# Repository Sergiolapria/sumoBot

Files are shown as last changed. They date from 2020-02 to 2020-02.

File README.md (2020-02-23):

# ROBOT DE MINISUMO

	Documentacion necesaria para la construccion de un robot de minisumo lo mas sencillo posible.

# ELECTRONICA
	
	Contiene la siguiente electronica:
-Modulo VL53L0X: para la medidion de la distancia a los objetos delante del robot.
-2 módulos de IR de siguelineas: seran los encargados de detectar en la parte del Dohyo en la que se encuentra.
-Driver L9110: Controla los motores.
-Arduino nano: posiblemente para comenzar la mejor opcion debido a su pequeño tamaño.

# DISEÑO

	El robot consta de 3 piezas:
-Chasis: En el iran ubicados los sensores IR, el driver de motores y los motores.
-Parte superior: Funciona  como sijeccion de los motores y llevara el sensor VL530LX asi como la pieza adaptador del Arduino nano.
-Adaptador: Alojara el arduino nano.

# LIBRERIAS:

-VL53L0X
-L9110.h( esta ultima la saque de http://bricolabs.cc/wiki/index.php?title=Sapoconcho)

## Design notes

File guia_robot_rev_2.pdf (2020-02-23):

GUIA PARA MONTAJE DE ROBOT MINISUMO DE MAKERSASTURIAS REV:2

Montaje de sensores IR:
Este sensor es el encargado de leer el suelo, es un sensor óptico reflexivo, la cantidad de luz reflejada depende del color por lo que podremos distinguir entre zonas claras y oscuras de un objeto. Contiene 2 partes, un diodo IR y un fototransistor en el cual incide la luz reflejada. A continuación se muestra la placa que acompaña a nuestro sensor. En el vemos que a parte de los pines de alimentación tenemos dos pines mas, el marcado por A0 es la señal analógica la cual da un valor en función de la luz que incide en el fototransistor, estas placas incluyen un amplificador operacional LM293 por lo cual nos dará una lectura digital cuando se supere cierto umbral.

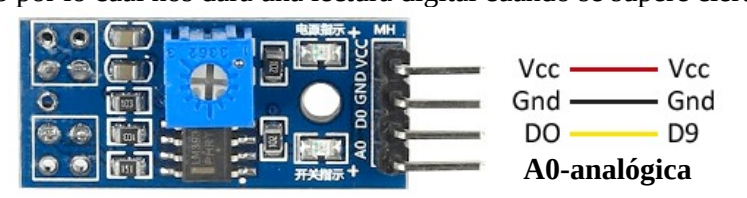
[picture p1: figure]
A0-analógica

Su ubicación es en el chasis colocandolos de la siguiente forma:

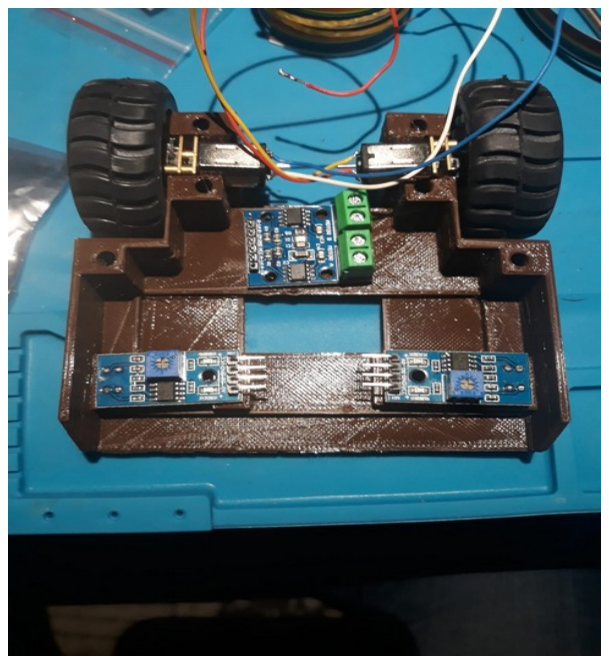
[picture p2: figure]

Para cablear y con el fin de descubrir por nosotros mismos la diferencia de trabajar con señales digitales y con señales analógicas cablearemos las dos.
El cableado al arduino ira de la siguiente manera:
MODULO IR | ARDUINO NANO
PIN | DESCRIPCIÓN | PIN
1-izquierda | Pin analógico izquierda | A0
2-izquierda | Pin digital izquierda | D2 | Pin digital 2(con la intención de habilitar int)
3-GND | Masa
4-Vcc | Alimentación 5V
1-derecha | Pin analógico derecha | A1
2-derecha | Pin digital derecha | D3 | Pin digital 3(con la intención de habilitar int)
3-GND | Masa
4-Vcc | Alimentación 5V

Montaje de sensor VL53L0X:
El VL53L0X es un sensor de distancia infrarrojo láser que mide un rango de distancias de 50 mm a 2000 mm, tiene mejor precisión a los sensores de ultrasonidos e infrarrojos y no se ve interferido por el ambiente como reflejos o ecos. Al ser láser tiene un ángulo de medición estrecho,
Twitter: @SergioPria | Pag. 1 de 6

REV:2

por lo cual solo leeremos la distancia que esta justamente en frente del sensor. Este ángulo de medición es de 25º, se traduce que a 1 m tenemos un área de 0,5 mm de diámetro.
Su colocacion en la parte superior sera de la siguiente forma:

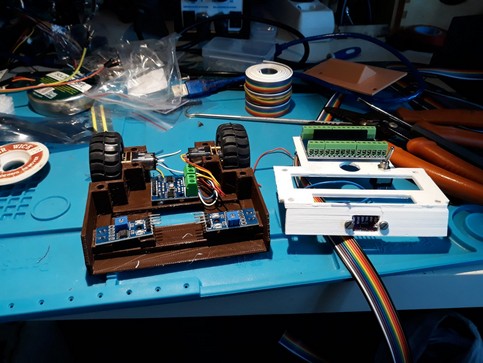
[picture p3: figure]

MODULO VL53L0X | ARDUINO NANO
PIN | DESCRIPCIÓN | PIN
Vin | Alimentación 3.3V
GND | Masa
SCL | | A5
SDA | | A4

Para el manejo del sensor VL53L0X utilizaremos la librería VL53L0X la cual se puede descargaren el repositorio de librerías del IDE de arduino. También se podría utilizar la librería de arduino. Montaje driver motores:
El driver esta basado en el puente en H L9110S el cual sirve para controlar un motor entre 2.5V y 12V con un consumo máximo de 800 mA pero la placa va provista de 2 integrados.
Como pines para controlar los motores utilizaremos los pines PWM del arduino nano D6,D9,D10 y D11.
La alimentación la haremos directamente desde la batería LiPo.
Para el manejo de los motores utilizaremos la librería de felixstdp realizada para el robot sapoconcho https://github.com/felixstdp/sapoconcho.
El cableado final quedara de la siguiente figura:

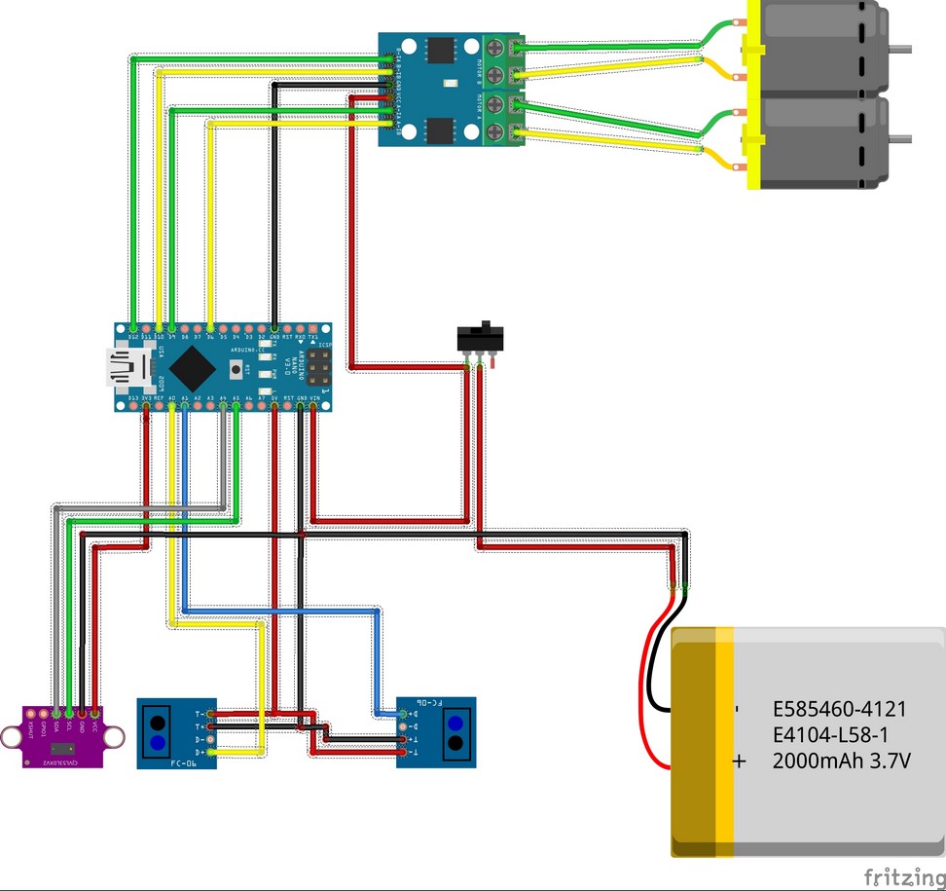
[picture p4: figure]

REV:2

Cableado:

Antes de comenzar a cablear debemos de disponer las diferentes placas que constituyes nuestro robot. En la parte inferior, yo lo llamo chasis, debemos de colocar los sensores IR, el driver para los motores y los motores, tal y como se muestra en la siguiente fotografia:

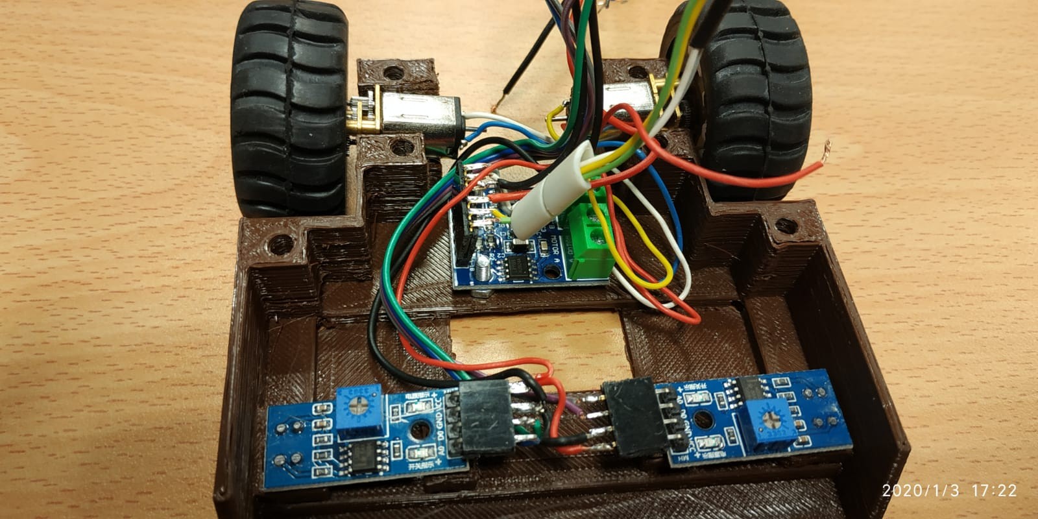
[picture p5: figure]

Es recomendable pegar los cables bien a la pared derecha o izaquierda con tal de que no nos estorben.
El siguiente paso seria soldar el interruptor y el conector de la bateria:

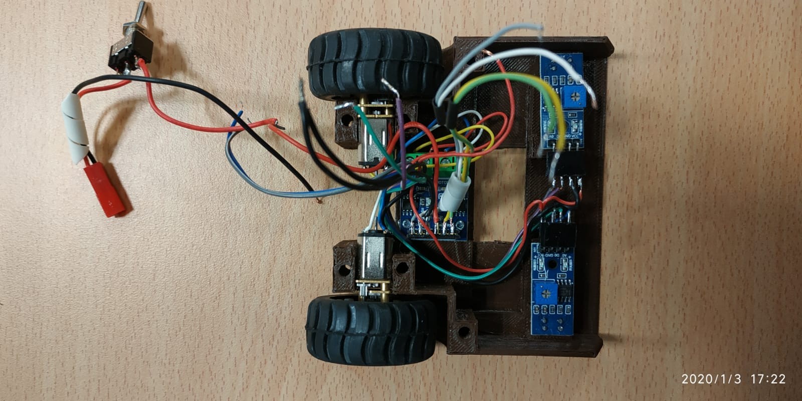
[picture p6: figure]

Si los sensores IR y el driver esta soldado sacamos los cables para arriba, ya que van a ir conectados al arduino nano, que va a ir a la parte superior.

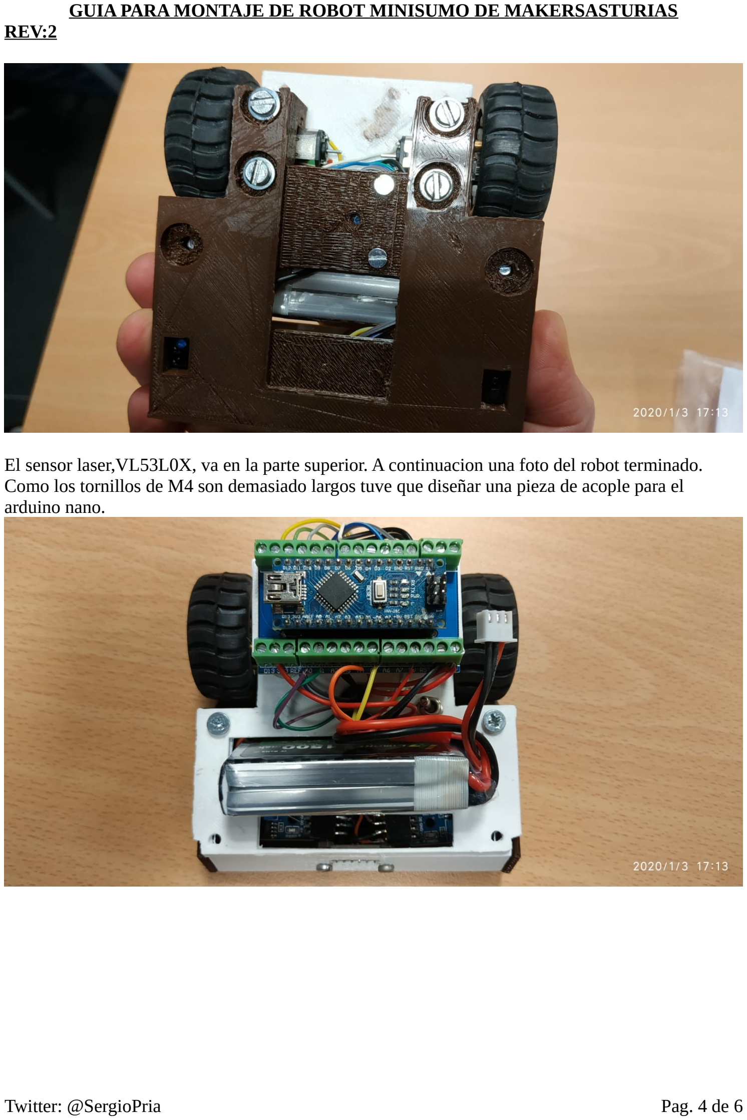
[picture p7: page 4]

REV:2

El sensor laser,VL53L0X, va en la parte superior. A continuacion una foto del robot terminado. Como los tornillos de M4 son demasiado largos tuve que diseñar una pieza de acople para el arduino nano.

REV:2

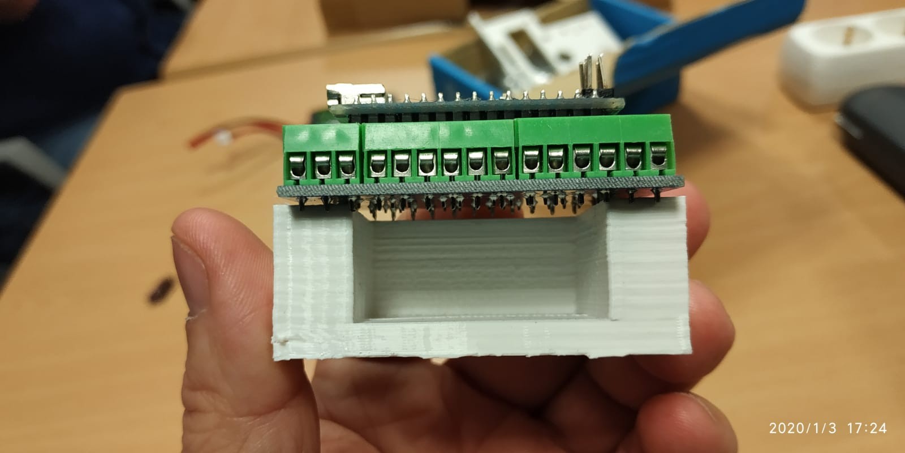
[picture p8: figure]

Programa:
Librerías necesarias:
-VL53L0X
-L9110.h

Bien si hay algun programador en la sala que me perdone por las burradas que voy a poner aquí.
En la tabla mostrada a continuacion se enumeran las distintas funciones asi como las variables necesarias para su funcionamiento y las variables devueltas.
FUNCION | DESCRIPCION | VARIABLES ENTRADA | VARIABLE SALIDA
laser_scan() | Lee el sensor laser y
| nos dice si el
| objetivo es target | int distance_thresh | boolean laser_status
floor_scan() | Lee los sensores IR
| y nos dice la
| ubicación en el
| DOHYO | Int floor_thresh | boolean floor_right_status
| | | boolean floor_left_status
adelante(int t1) | Marcha hacia
| adelante un t1 y para | int t1
derecha(int t1) | Giro a derecha un
| tiempo t1 | int t1
izquierda(int t1) | Giro izquierda un
| tiempo t1 | int t1
atras(int t1) | Marca hacia atrás un
| tiempo t1 | int t1

En la funcion principal, void loop(), lo que hacemos es llamar a las funciones anteriormente enumeradas. Esta llamamiento deberemos de hacerlo con lógica , esto creo que se llama programacion orientada a objetos????. Como ejemplo enumero como seria el loop:

REV:2

void loop(){
laser_scan(); //leemos el laser if(laser_status==true){ //si pillamos algo adelante(20);
}
else{
izquierda(10); //sino pillamos nada giramos un poco y volvemos a hacer la misma maniobra
}
}
En el siguiente ejemplo ya incluimos la lectura del suelo, la lectura de los sensores IR
Tuneos:
A nivel de software y hardware se podría hacer posible tener varias estrategias a desarrollar en función del botón presionado. Para esto seria interesante utilizar la botonera del “escornabot” de 3 pines. Esta botonera utiliza como señal un solo pin analógico. Las estrategias serian en función de como seria el combate, ya que puedes empezar enfrentándote de frente, de lado o de espaldas.

A nivel mecánico se podría poner un servo encima que accionase una bandera, esta bandera bajada al ras del suelo podría confundir al contrincante que iría contra ella y no contra nosotros.

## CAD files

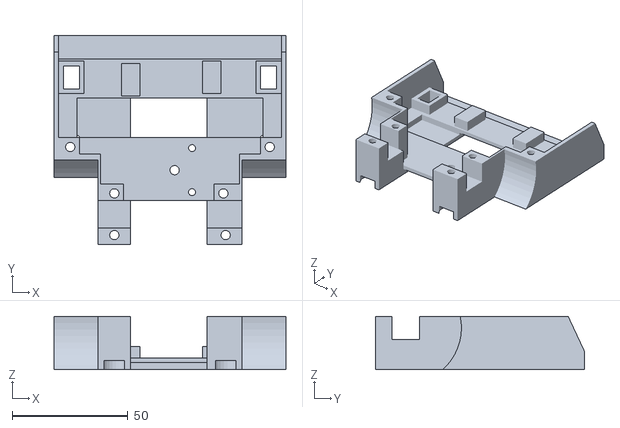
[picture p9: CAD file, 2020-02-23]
draws/chasis.stl
100.0 x 90.0 x 23.0

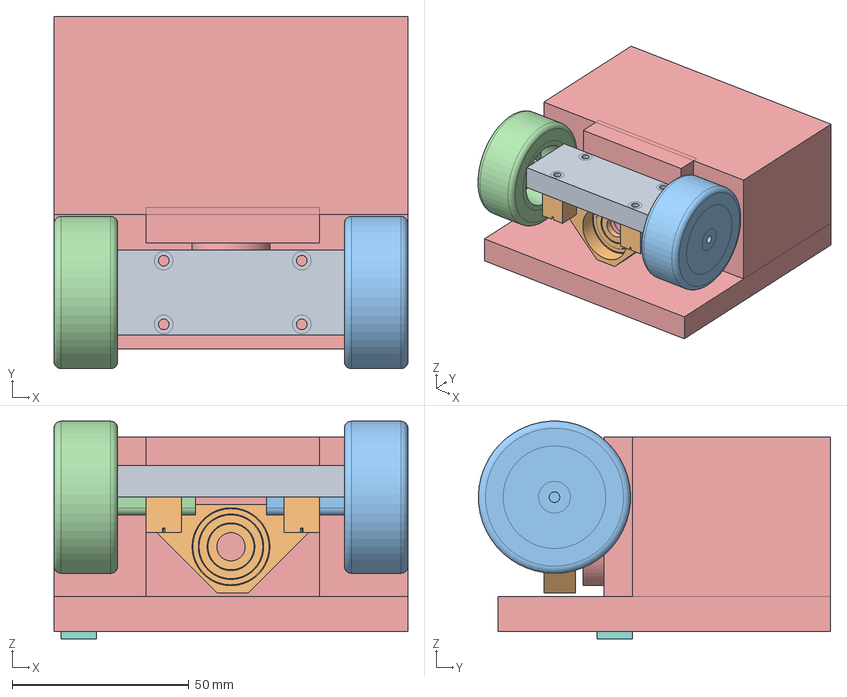
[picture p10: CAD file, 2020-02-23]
draws/ROBOT_SUMO2.FCStd
100.0 x 99.5 x 61.5 mm
traccion004
traccion005
Cubo011

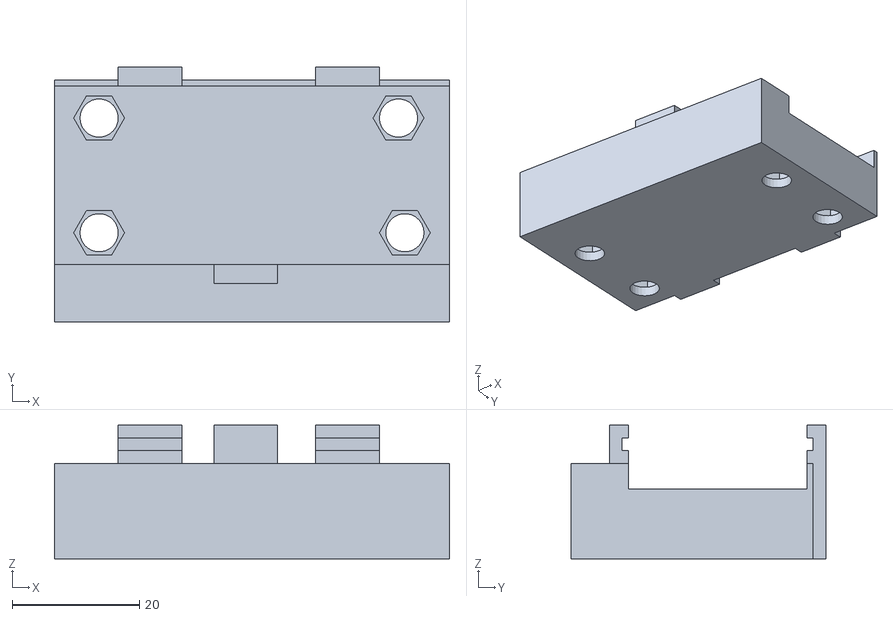
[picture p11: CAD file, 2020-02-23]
draws/adaptador.stl
62.0 x 40.0 x 21.0

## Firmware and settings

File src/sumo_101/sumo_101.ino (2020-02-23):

//programa 101 para sumo de MAKERSATURIAS
//Realiza una estrategia basica de escaneo y ataque
//(CC) 2019 Sergio Lopez .@SergioPria
#include "L9110.h"
#include <VL53L0X.h>
#include <Wire.h>

#define analog_right 0
#define analog_left 1
//Variables
int distance=0;
int val_floor_right=0;
int val_floor_left=0;
int distance_thresh=300;
int floor_thresh=100;

bool laser_status=false;
bool floor_right_status=false;
bool floor_left_status=false; 

//Constructores
L9110 bot(6,9,10,11);
VL53L0X laser; 
void setup() {
  Serial.begin(9600); //seria para comprobar el funcionamiento del robot, debugg que dicen los estudiaos
  Wire.begin();// inicializamos Wire, el protocolo i2c
  laser.init();//inicializamos laser
  laser.setTimeout(500);
  laser.startContinuous();
  delay(5000);//retraso de 5 sg
}

void loop() {
  floor_scan();
  laser_scan();
  report_serial();
  if(val_floor_right==true && val_floor_left==true){ //esta dentro del sohyo
    laser_scan();
    
  if(laser_status==true){
    adelante(10);
  }
  else{
    derecha(10);  
  }
  }else{
    if(val_floor_right==true && val_floor_left==false){ //se necesita girar derecha
      atras(20);
      derecha(10);
    }
    if(val_floor_right==false && val_floor_left==true){ //se necesita girar izquierda
      atras(20);
      izquierda(10);      
    }
    if(val_floor_right==false && val_floor_left==false){
      atras(20);
    }
  }
}

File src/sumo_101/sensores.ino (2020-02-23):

void laser_scan(){
  distance=laser.readRangeContinuousMillimeters();
  if(laser.timeoutOccurred()){
    Serial.println("TIMEOUT");
  }
  if(distance<distance_thresh){
    laser_status=true;
  }
  else{
    laser_status=false;
  }
}
void floor_scan(){
  val_floor_right=analogRead(0);
  val_floor_left=analogRead(1);
  if(val_floor_right>floor_thresh){
    floor_right_status=false;
  }
  else{
    floor_right_status=true;
  }
  if(val_floor_left>floor_thresh){
    floor_left_status=false;
  }
  else{
    floor_left_status=true;
  }
}
void report_serial(){
  Serial.print("DISTANCIA : ");
  Serial.print(distance);
  Serial.print(" | ");
  Serial.print("IR DERECHO : ");
  Serial.print(val_floor_right);
  Serial.print(" | ");
  Serial.print("IR IZQUIERDO : ");
  Serial.print(val_floor_left);
  Serial.print(" | ");
  if(laser_status==true){
    Serial.print("ADELANTE");
  }
  else{
    Serial.print("SCAN");
  }
  Serial.println("");
}

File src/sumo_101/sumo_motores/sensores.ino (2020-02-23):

void laser_scan(){
  distance=laser.readRangeContinuousMillimeters();
  Serial.print("DISTANCIA : ");
  Serial.println(distance);
  if(laser.timeoutOccurred()){
    Serial.println("TIMEOUT");
  }
  if(distance<distance_thresh){
    laser_status=true;
  }
  else{
    laser_status=false;
  }
}
void floor_scan(){
  val_floor_right=analogRead(analog_right);
  val_floor_left=analogRead(analog_left);
  Serial.print(val_floor_right);
  Serial.print(" : ");
  Serial.println(val_floor_left);
  if(val_floor_right<floor_thresh){
    floor_right_status=true;
  }
  else{
    floor_right_status=false;
  }
  if(val_floor_left<floor_thresh){
    floor_left_status=true;
  }
  else{
    floor_left_status=false;
  }
}
